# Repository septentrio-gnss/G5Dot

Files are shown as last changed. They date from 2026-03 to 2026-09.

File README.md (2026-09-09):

# G5Dot

| Role | Contact |
|---|---|
| Author | [laekaz](https://github.com/laekaz) |
| Maintainer  | [Septentrio GNSS GitHub User](githubuser@septentrio.com) |
| License | Open-Source Hardware License (CERN-OHL) |

<p align="center">
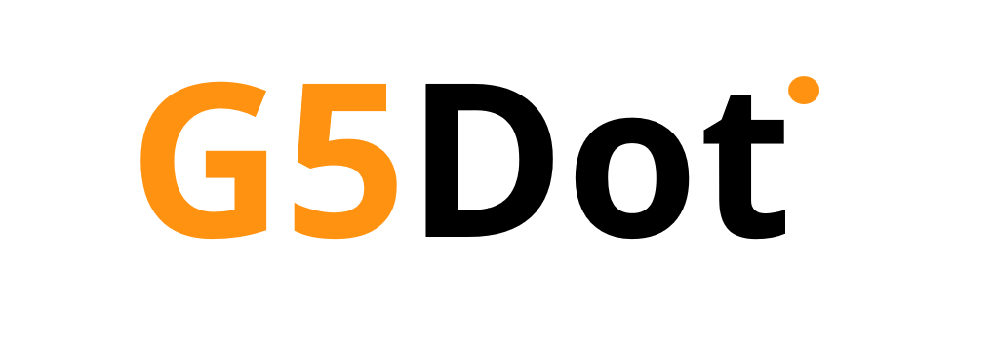
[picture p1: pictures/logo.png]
  
</p>
<p align="center">
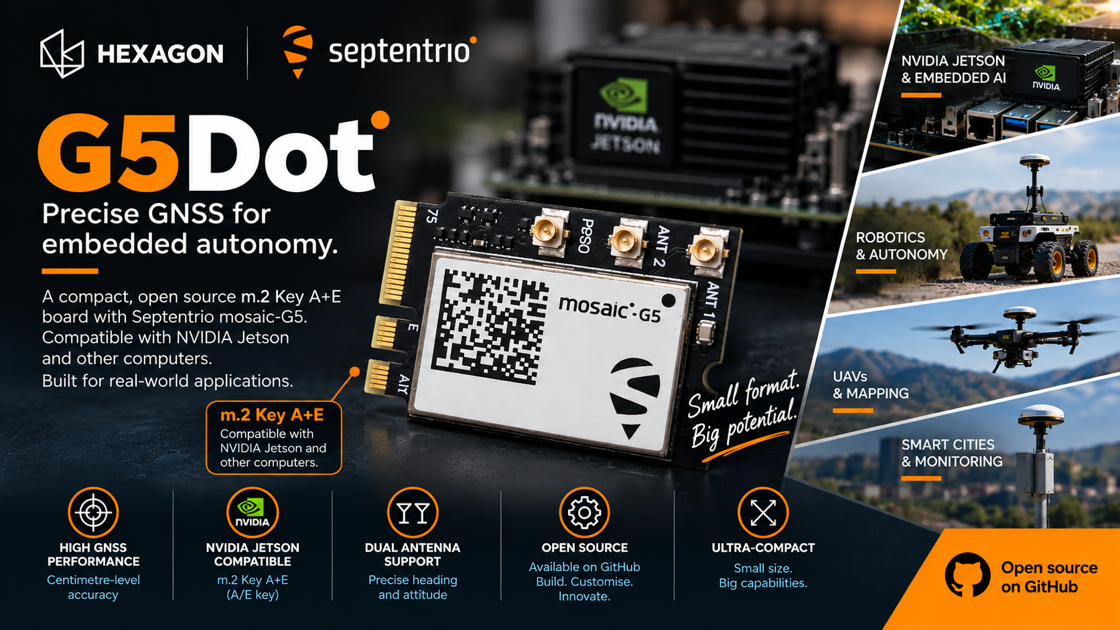
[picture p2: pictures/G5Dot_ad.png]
ad
  
</p>

This open source project is derived from the following original project located [here](https://github.com/anavsgmbh/M2_Mosaic-G5_Smart/tree/main)

# Table of Contents
* [Introduction to G5Dot](#introduction-to-g5dot)
  * [What is a G5Dot?](#what-is-a-g5dot)
  * [Who is Septentrio?](#who-is-septentrio)
  * [Where can I buy it?](#where-can-i-buy-it)
    * [Who is ANavS GmbH?](#who-is-anavs-gmbh)
* [Technology](#technology)
  * [What is a mosaic-G5 module?](#what-is-a-mosaic-g5-module)
  * [Other mosaic-G5 versions](#other-mosaic-g5-versions)
* [Why Open Source](#why-open-source)
* [Disclaimer](#disclaimer)
* [How to Produce](#how-to-produce)
  * [Deliverables](#deliverables)
  * [Ordering the mosaic-G5 Module](#ordering-mosaic-g5-module)
* [M.2 Form Factor](#m2-form-factor)
  * [Why M.2?](#why-m2)
  * [Why for NVIDIA?](#why-for-nvidia)
* [User Documentation](#user-documentation)
  * [Interfaces](#interfaces)
  * [Insert in NVIDIA Orin Development Kit](#insert-in-nvidia-orin-development-kit)
  * [Pinout for M.2 Key A+E Connector](#pinout-for-m2-key_ae-connector)
  * [Pinout for mosaic-G5 Module](#pinout-for-mosaic-g5-module)
  * [Antenna](#antenna)
  * [How to Get GNSS Data](#how-to-get-gnss-data)

* [Interface, Protocol & Electrical Specifications](#interface-protocol--electrical-specifications)

# Introduction to G5Dot
## What is a G5Dot?
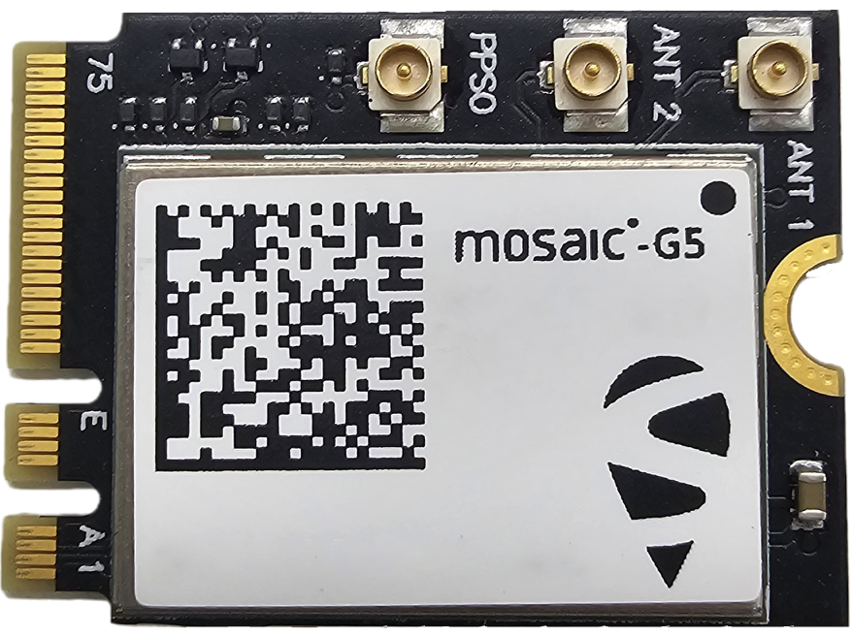
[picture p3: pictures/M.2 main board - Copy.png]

This is a compact, high precision GNSS (Global Navigation Satellite System) receiver card design for embedded computing platforms, ideal for industrial PCs such as NVIDIA Jetson. Its small size and low power consumption make it appropriate for applications where space and efficiency are critical. 

The design is based on the mosaic-G5 GNSS receiver, which supports multiple satellite systems and enables centimetre-level positioning accuracy. This open-source board was originally designed by ANavS GmbH.
## Who is Septentrio?


Septentrio is a leading company that designs, manufactures and sells high precision and multi-frequency GPS/GNSS receivers for demanding applications. Septentrio products are used in different industries including automotive, marine, construction, rail, machine control, logistics, precision agriculture, geographic information systems (GIS), Unmanned aerial vehicles (UAVs), survey, mapping and scientific applications. Septentrio’s receivers constantly deliver highly accurate and precise GNSS positioning, scalable to centimetre-level and designed to perform perfectly in challenging environments. 

Septentrio's technology offers high accuracy and reliability thanks to advanced GNSS algorithms as well as [Advanced interference Monitoring and mitigation (AIM+)](https://www.septentrio.com/en/learn-more/advanced-positioning-technology/aim-anti-jamming-protection) This protects your application against jamming (RF interference) and spoofing (malicious attacks).

For more information about Septentrio products go to [**https://www.septentrio.com/**](https://web.septentrio.com/GH-SSN-home).

## Where can i buy it?
The board is available for purchase from ANavS

Website: https://anavs.com/products/embedded-modules/gnss-card-g5/

### Who is ANavS GmbH
ANavS GmbH is a German company that develops high precision navigation and positioning systems. Their technology combines GNSS, inertial sensors (IMUs), and sensor fusion algorithms to provide accurate location and orientation.

For more details, visit the product page [here](https://anavs.com/products/embedded-modules/gnss-card-g5/) 

# Technology 
## What is a mosaic-G5 module?
The mosaic-G5 is a compact GNSS receiver module from Septentrio, engineered for high reliability and precise positioning. It integrates the latest multi-band, multi-constellation GNSS technology, providing accurate positions while minimizing power consumption. The receiver can access signals from all major satellite constellations, including GPS, Galileo, GLONASS, and BeiDou.

Different versions of the mosaic-G5 are available to suit various applications, as summarized below:

| Features | [mosaic-G5 P1](https://www.septentrio.com/en/products/gnss-receivers/gnss-receiver-modules/mosaic-g5-p1) | [mosaic-G5 P3](https://www.septentrio.com/en/products/gnss-receivers/gnss-receiver-modules/mosaic-G5-P3) | [mosaic-G5 P3H](https://www.septentrio.com/en/products/gnss-receivers/gnss-receiver-modules/mosaic-G5-P3H) |
|---|---|---|---|
| Functionality|High-precision positioning |High-precision positioning |Positioning + Heading|
| Use case |Robotics (e.g robotic mowers), GIS devices |UAV, Commercial mowers, Industrial Robotics, GIS and mapping applications |UAV, Commercial mowers, Industrial Robotics,GIS, mapping applications, sensor fusion and INS systems| 
| GNSS bands | Triple-band  | Quad-band | Quad-band |
| RTK support  | Yes | Yes | Yes |
| Dual antenna | | | Yes |
| Heading | | | Yes |

## Other mosaic-G5 versions
 You can use other [mosaic modules](https://www.septentrio.com/en/products/gnss-receivers?f%5B0%5D=type%3A604), but you need to pay attention to the functions and pins that could be exposed, then modify the design for your own project. 

## Why open-source 
This board is open-source to encourage collaboration, customization, and innovation. It makes it easy for developers, hobbyists, and integrators to combine high-precision GNSS positioning with platforms like NVIDIA, experiment, create spin-off projects, and adapt it for a wide range of robotics, autonomous systems, or industrial applications.

Open-source promotes shared development, letting users build on existing work and push the technology further. It also means you have access to editable design files and are free to modify, build or sell your own version.

## Disclaimer
This project is offered as-is. The main interfaces have been tested, but the design has not been fully checked or approved by the author or Septentrio. You are responsible for how you use it in your own projects. For guidance on working with Septentrio’s GNSS mosaic modules, we suggest reaching out to Septentrio directly.

Support website: https://www.septentrio.com/en/support

# How to produce
## Deliverables
This open-source project contains the following files for designers, producers and integrators around Septentrio's mosaic modules.

Both **Altium Designer** and **KiCad** design files are provided. You can choose either format according to your preferred PCB design workflow.

### Altium Designer

|Files |Description | 
|---|---|
|[G5Dot.PrjPcb](/G5Dot/G5Dot/G5Dot.PrjPcb) |Altium Project |
|[Cover_Page.SchDoc](/G5Dot/G5Dot/Cover_Page.SchDoc) |Cover page |
|[M.2_Key_A+E.SchDoc](/G5Dot/G5Dot/M.2_Key_A+E.SchDoc) |Schematics for M.2 KEY A+E |
|[Mosaic-G5.SchDoc](/G5Dot/G5Dot/Mosaic-G5.SchDoc) |Schematics for mosaic-G5 P3 module|
|[G5Dot.PrjPcbVariants](/G5Dot/G5Dot/G5Dot.PrjPcbVariants) |Introduction and variants |
|[BOM_G5Dot_REV_01.01_VARIANT_Mosaic-G5_P3H.xlsx](/BOM_G5Dot_REV_01.01_VARIANT_Mosaic-G5_P3H.xlsx)|Bill of Materials |
|[G5Dot_Schematics.pdf](/G5Dot_Schematics.pdf) |Schematics PDF |

### KiCad

| File | Description |
|---|---|
| [G5Dot.kicad_pro](./G5Dot/G5Dot%20Kicad/G5Dot.kicad_pro) | KiCad project |
| [Cover_Page.kicad_sch](./G5Dot/G5Dot%20Kicad/Cover_Page.kicad_sch) | Cover page schematic |
| [M.2_Key_A+E.kicad_sch](./G5Dot/G5Dot%20Kicad/M.2_Key_A+E.kicad_sch) | Schematics for the M.2 Key A+E interface |
| [Mosaic-G5.kicad_sch](./G5Dot/G5Dot%20Kicad/Mosaic-G5.kicad_sch) | Schematics for the mosaic-G5 P3 module |

## Ordering mosaic-G5 module

You can order the mosaics from Digi-Key, or you can contact Septentrio directly.

| mosaic-G5 versions | Septentrio | Digi-Key part_number| CompoTEK |
|---|---|---|---|
| mosaic-G5 P1 |[Septentrio_G5-P1](https://www.septentrio.com/en/products/gnss-receivers/gnss-receiver-modules/mosaic-g5-p1) | - |-|
| mosaic-G5 P3 | [Septentrio_G5-P3](https://www.septentrio.com/en/products/gnss-receivers/gnss-receiver-modules/mosaic-G5-P3) | [410501](https://www.digikey.com/en/products/detail/septentrio-inc/410501/28527327) | [sep_mosaic-G5_P3](https://shop.compotek.de/products/mosaic-G5-P3-p789238026)|
| mosaic-G5 P3H |[Septentrio_G5-P3H](https://www.septentrio.com/en/products/gnss-receivers/gnss-receiver-modules/mosaic-G5-P3H) | [410502](https://www.digikey.com/en/products/detail/septentrio-inc/410502/28527213) | [sep_mosaic-G5_P3H](https://shop.compotek.de/products/mosaic-G5-P3H-p790005981)|
|G5Dot| - | [100040](https://www.digikey.com/en/products/detail/anavs-gmbh/100040/28164182) |- |

# M.2 form factor
## Why M.2?
M.2 form factor is a standard interface used to provide a compact and flexible way to add extra functionality without redesigning the hardware. It is usually used in Laptops for Wi-Fi or SSDs, industrial PCs and embedded boards such as NVIDIA Jetson. 

The M.2 Key A+E connector can fit into a Key E and Key A slots. Key A and Key E modules are mechanically compatible with both Key A and Key E slots.  

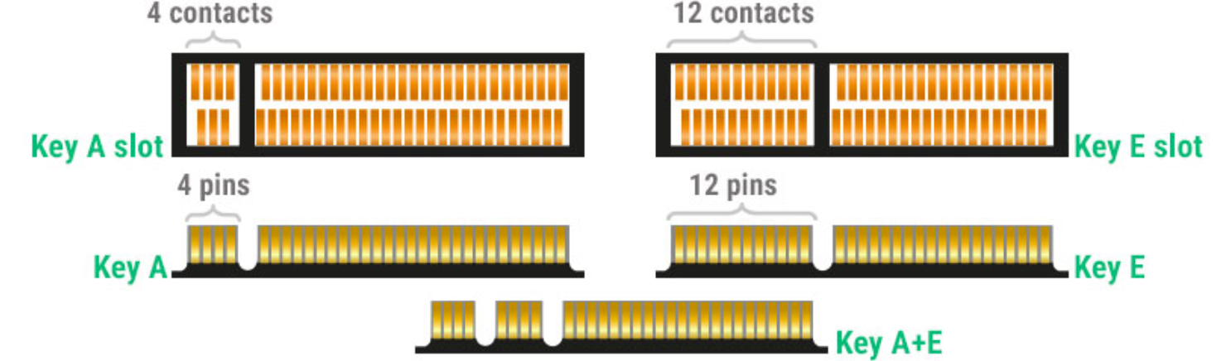
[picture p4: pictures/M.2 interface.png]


## Why for NVIDIA?
NVIDIA Jetson boards are small powerful AI computers designed for applications like robotics, drones and smart systems. They provide powerful GPU performance in a compact, energy-efficient system, making them ideal for real-time AI and embedded development.

Using the M.2 form factor for the mosaic-G5, allows developers already working in the NVIDIA ecosystem to easily add the GNSS module without redesigning their hardware.

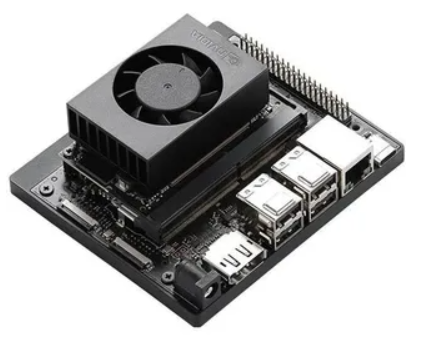
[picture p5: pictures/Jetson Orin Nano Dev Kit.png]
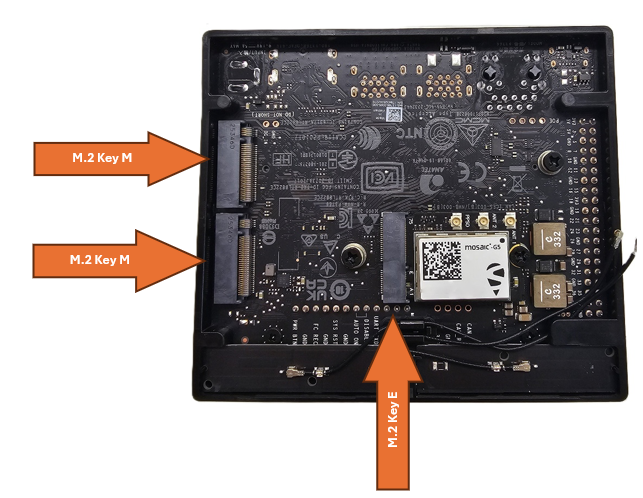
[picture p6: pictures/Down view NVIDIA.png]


# User documentation

## Interfaces
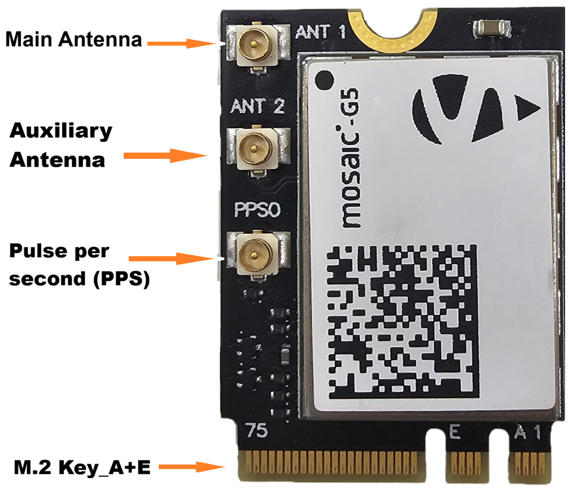
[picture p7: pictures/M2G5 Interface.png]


## Insert in NVIDIA Orin development kit
G5Dot can be easily connected to the NVIDIA Jetson board as shown: 

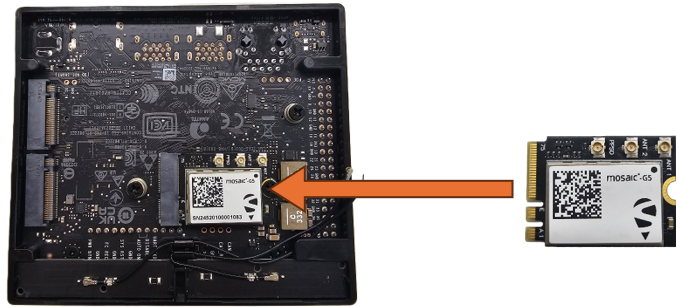
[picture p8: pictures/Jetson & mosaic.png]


You can insert the board on the underside of the NVIDIA Jetson board 

## Pinout for M.2 Key_A+E Connector 
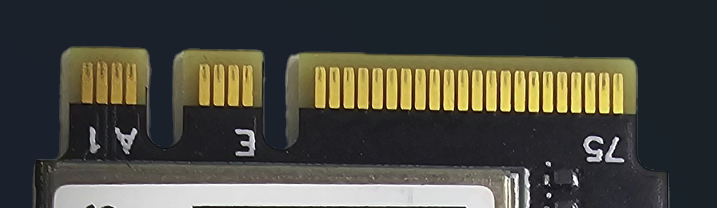
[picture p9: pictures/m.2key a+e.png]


| Pin # |Signal to the mosaic module|
|---|---|
| 3	 |USB D+ |
| 5	 |USB D- |
| 2,4,72,74	|power 3.3 V |
| 6 |External LED | 
| 16 | External LED | 
| GND	 |GND |

* USB: the USB interface handles both data communication and receiver configurations. Through this connection, the GNSS receiver module can send positioning data, satellite information, and timing messages.

* Power: the board is powered via 3.3 V supply lines on multiple pins to ensure stable operation. A clean and stable power source is important for reliable GNSS performance.

* LED: these pins can be used to drive external LEDs, which are helpful for quick visual feedback

## Pinout for mosaic-G5 module

| Pin # |mosaic module signals|
|---|---|
|2 |Antenna |
|5 |Antenna |
|12	 |USB D+ |
|13 |USB D- |
|14 |VBUS |
|42 | Pulse Per Second |
|44, 45 |power 3.3 V |
|52 |External LED | 
|53 | External LED | 
|54 |Antenna power 3.3 V  |
| GND	  |GND |

## Antenna

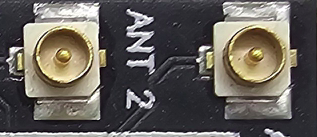
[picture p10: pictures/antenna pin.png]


The board exposes two RP-UMRF (micro RF) antenna connectors for GNSS signal reception. These connectors are designed for 50 Ω antennas and provide the interface for connecting external GNSS antennas to the module.

The connectors typically serve as MAIN (primary) and AUX (secondary) inputs, enabling support for advanced features such as dual-band reception and high-precision positioning (e.g., RTK)

## How to get GNSS Data
* Insert the G5Dot into the M.2 slot.
* Connect the GNSS antenna to the antenna connector
* Configure the receiver 

## Interface, Protocol & Electrical Specifications
Interface
* USB (device 2.0 HS up to 480 Mbps)
* Configure PPS via the u.FL connector

Protocols
* SBF (Septentrio Binary Format)
* NMEA
* RTCM v3.x (MSM included)

The official Septentrio mosaic-G5 driver can be used

Electrical
* Input voltage: 3.3 V +/- 5%
* Power consumption:
 * Typical: 0.4-0.6 W 
 * Max: 0.9 W 
* Antenna bias voltage: 3.3 V

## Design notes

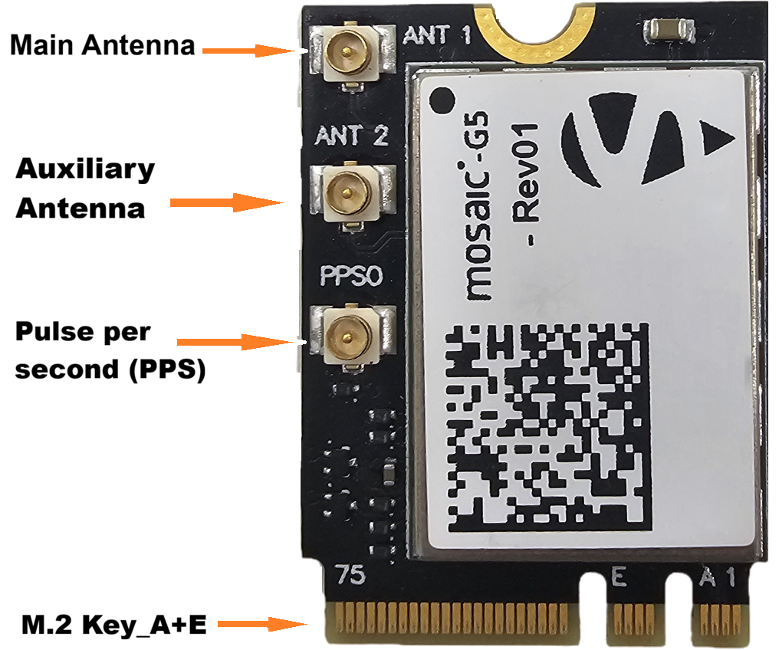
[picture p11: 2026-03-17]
pictures/M2G5 Interface black (2).png

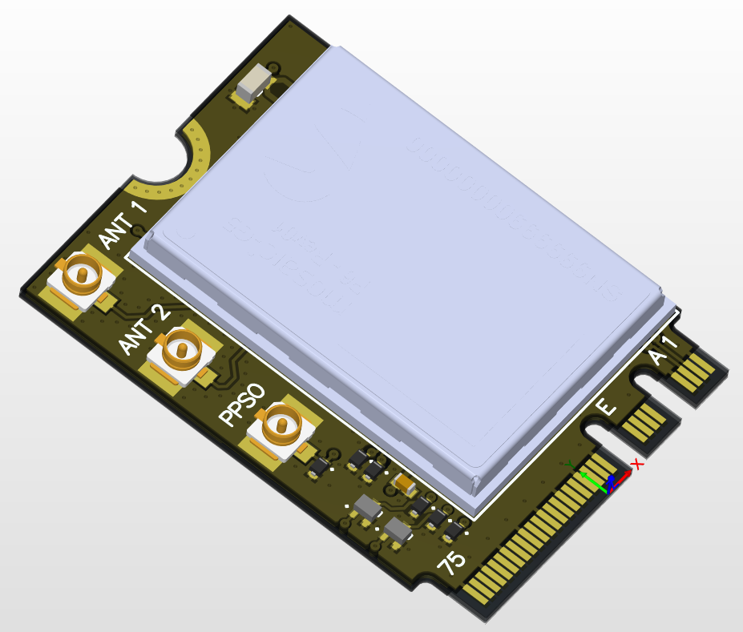
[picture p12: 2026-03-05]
preview.png

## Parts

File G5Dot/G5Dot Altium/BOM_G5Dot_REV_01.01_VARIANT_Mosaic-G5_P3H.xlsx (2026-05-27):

 | Bill of Materials
 | Project Title: | BOM for Variant [Mosaic-G5_P3H] of BOM Document [G5Dot.BomDoc] |  |  |  |  | Geenhill Campus
 | Project File Name: | G5Dot.PrjPcb |  |  |  |  | Interleuvenlaan 15i
 | Assembly Variant: | Mosaic-G5_P3H |  |  |  |  | 3001 Leuven
 | Report Date: | 12.06.2025 | 11:15 |  |  |  | Belgium
Name | Description | Designator | Quantity | Manufacturer1 | MPN1 | Supplier1 | SPN1
C1608X5R0J226M080AC | MLCC, 22 uF, 0603, 6.3 V, 20%, X5R | C1 | 1 | TDK | C1608X5R0J226M080AC | Newark | 04X3240
GCM155R71H104KE02D | MLCC, 100 nF, 0402, 50 V, 10%, X7R | C2 | 1 | Murata | GCM155R71H104KE02D | Newark | 96Y9214
ESD9R3.3ST5G | ESD9R3.3S Series 4.8 V 0.5 pF Uni-Directional ESD Protection Diode - SOD-923 | D1, D2, D3, D4, D5, D6 | 6 | ON Semiconductor | ESD9R3.3ST5G | Newark | 13P3802
636101112001 | Rf Conn, Umrf, Jack, 50 Ohm, Pcb Rohs Compliant: Yes | J2, J3, J4 | 3 | Wurth Electronics | 636101112001 | Digikey | 732-636101112001CT-ND
NTK3043NT1G | Single N-Channel Small Signal MOSFET with ESD Protection 20V, 285mA, 3.4Ω | Q1, Q2 | 2 | ON Semiconductor | NTK3043NT1G | Mouser | 863-NTK3043NT1G
mosaic-G5-P3H | mosaic-G5 GNSS Module - Low-power multi-band multi-constellation GNSS receiver. | U1 | 1 | Septentrio | 410502 | Digikey | 2771-410502-ND
PCB | Printed Circuit Board | UF1 | 1

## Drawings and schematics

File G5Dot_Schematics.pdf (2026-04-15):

# M.2 Dual Key A+E Card with Mosaic-G5 GNSS Module

# Low-power multi-band multi-constellation GNSS receiver

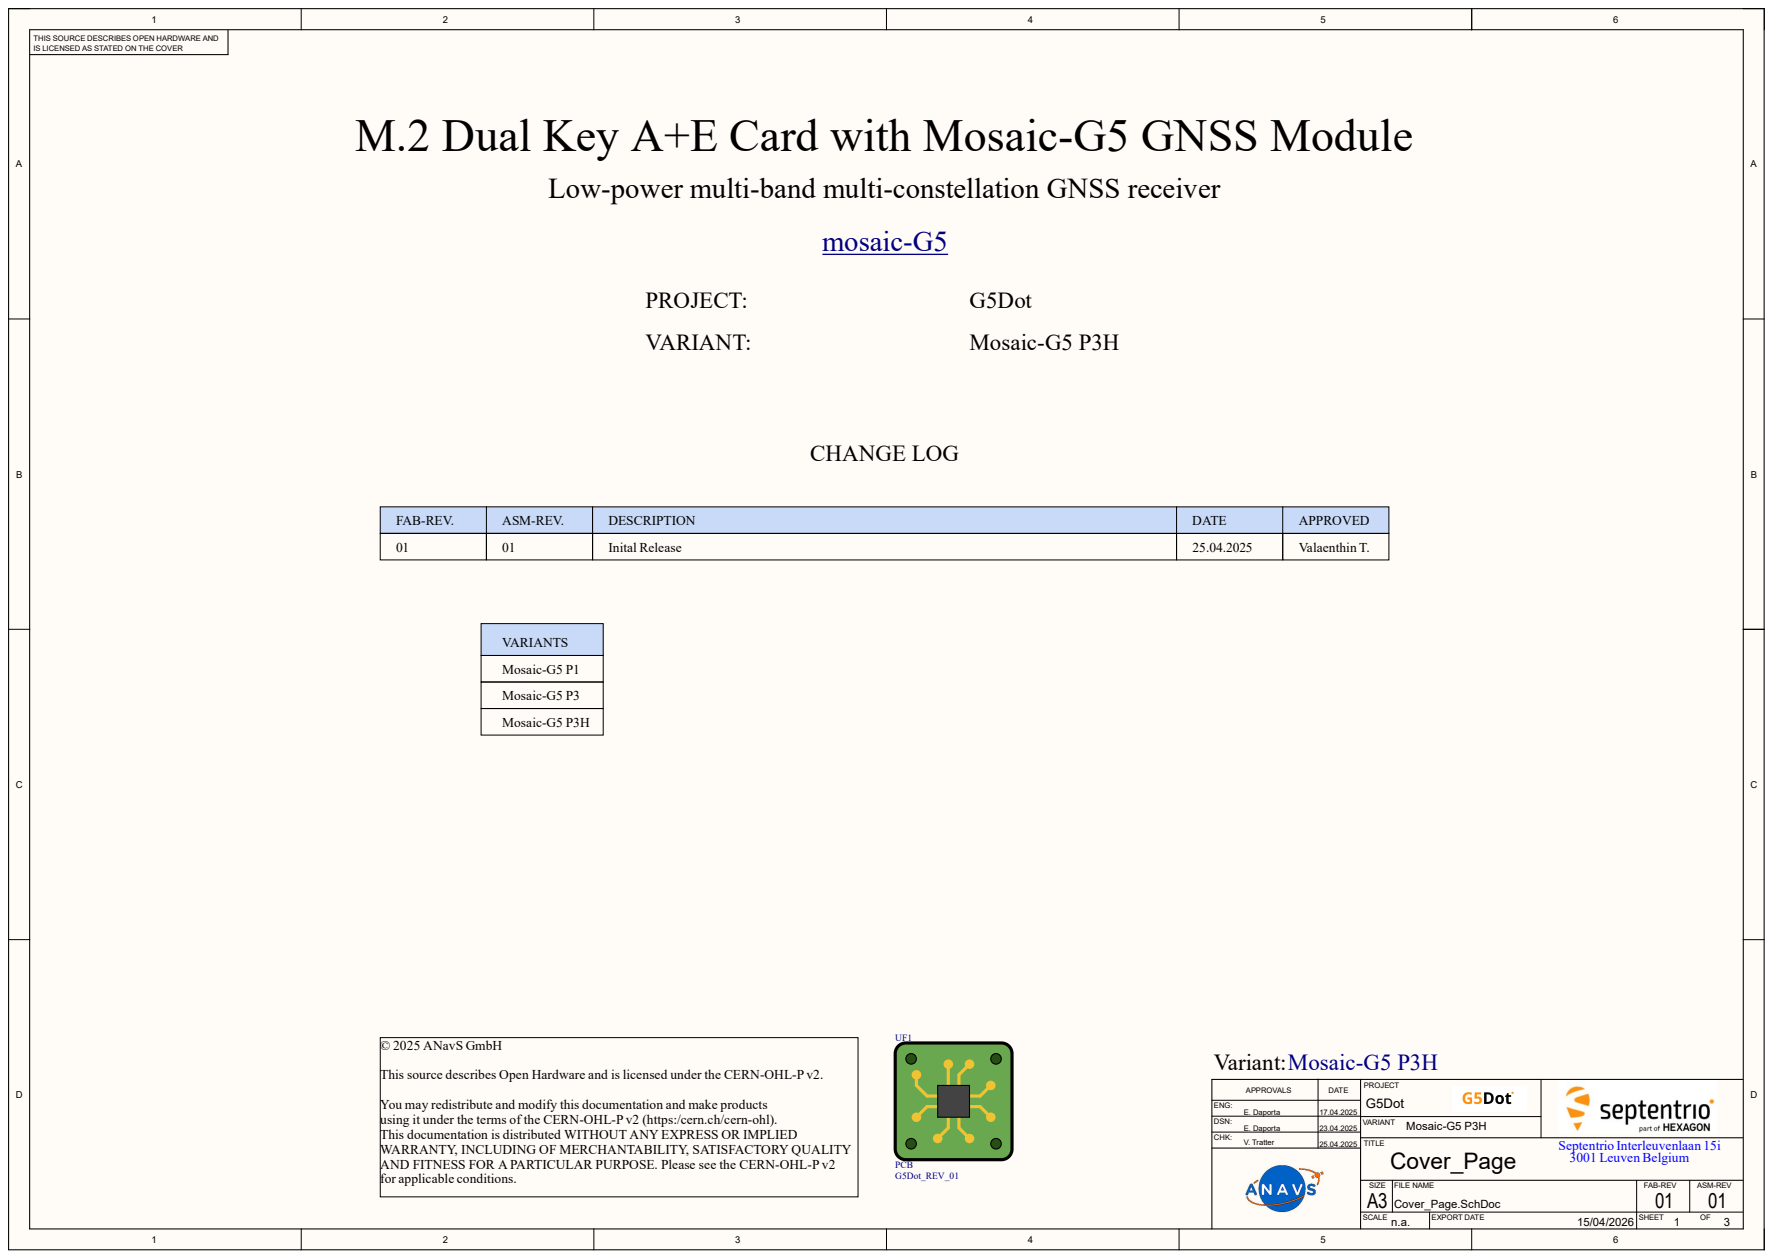
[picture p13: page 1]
Cover_Page; TITLE; Variant:Mosaic-G5 P3H; mosaic-G5; ASM-REV.; DESCRIPTION; DATE; APPROVED; 01 Inital Release; FAB-REV.; Valaenthin T.; CHANGE LOG; © 2025 ANavS GmbH; PROJECT:; G5Dot; VARIANT:; Mosaic-G5 P3H; Septentrio Interleuvenlaan 15i; G5Dot_REV_01; PCB; VARIANTS; Mosaic-G5 P1; Mosaic-G5 P3; 3001 Leuven Belgium

THIS SOURCE DESCRIBES OPEN HARDWARE AND
IS LICENSED AS STATED ON THE COVER

This source describes Open Hardware and is licensed under the CERN-OHL-P v2.

APPROVALS | DATE | PROJECT G5Dot | Septentrio * Belgium

You may redistribute and modify this documentation and make products
using it under the terms of the CERN-OHL-P v2 (https:/cern.ch/cern-ohl).
This documentation is distributed WITHOUT ANY EXPRESS OR IMPLIED
WARRANTY, INCLUDING OF MERCHANTABILITY, SATISFACTORY QUALITY
AND FITNESS FOR A PARTICULAR PURPOSE. Please see the CERN-OHL-P v2
for applicable conditions.

ENG: E. Daporta | 17.04.2025
DSN: E. Daporta | 23.04.2025 | VARIANT Mosaic-G5 P3H
CHK: V. Tratter | 25.04.2025

SIZE A3 Cover_Page.SchDoc | FILE NAME | FAB-REV | ASM-REV 01

SCALE n.a. | 15/04/2026 EXPORT DATE | SHEET OF

## M.2 Key A+E Card

# M.2 Dual Key A+E Edge Connector

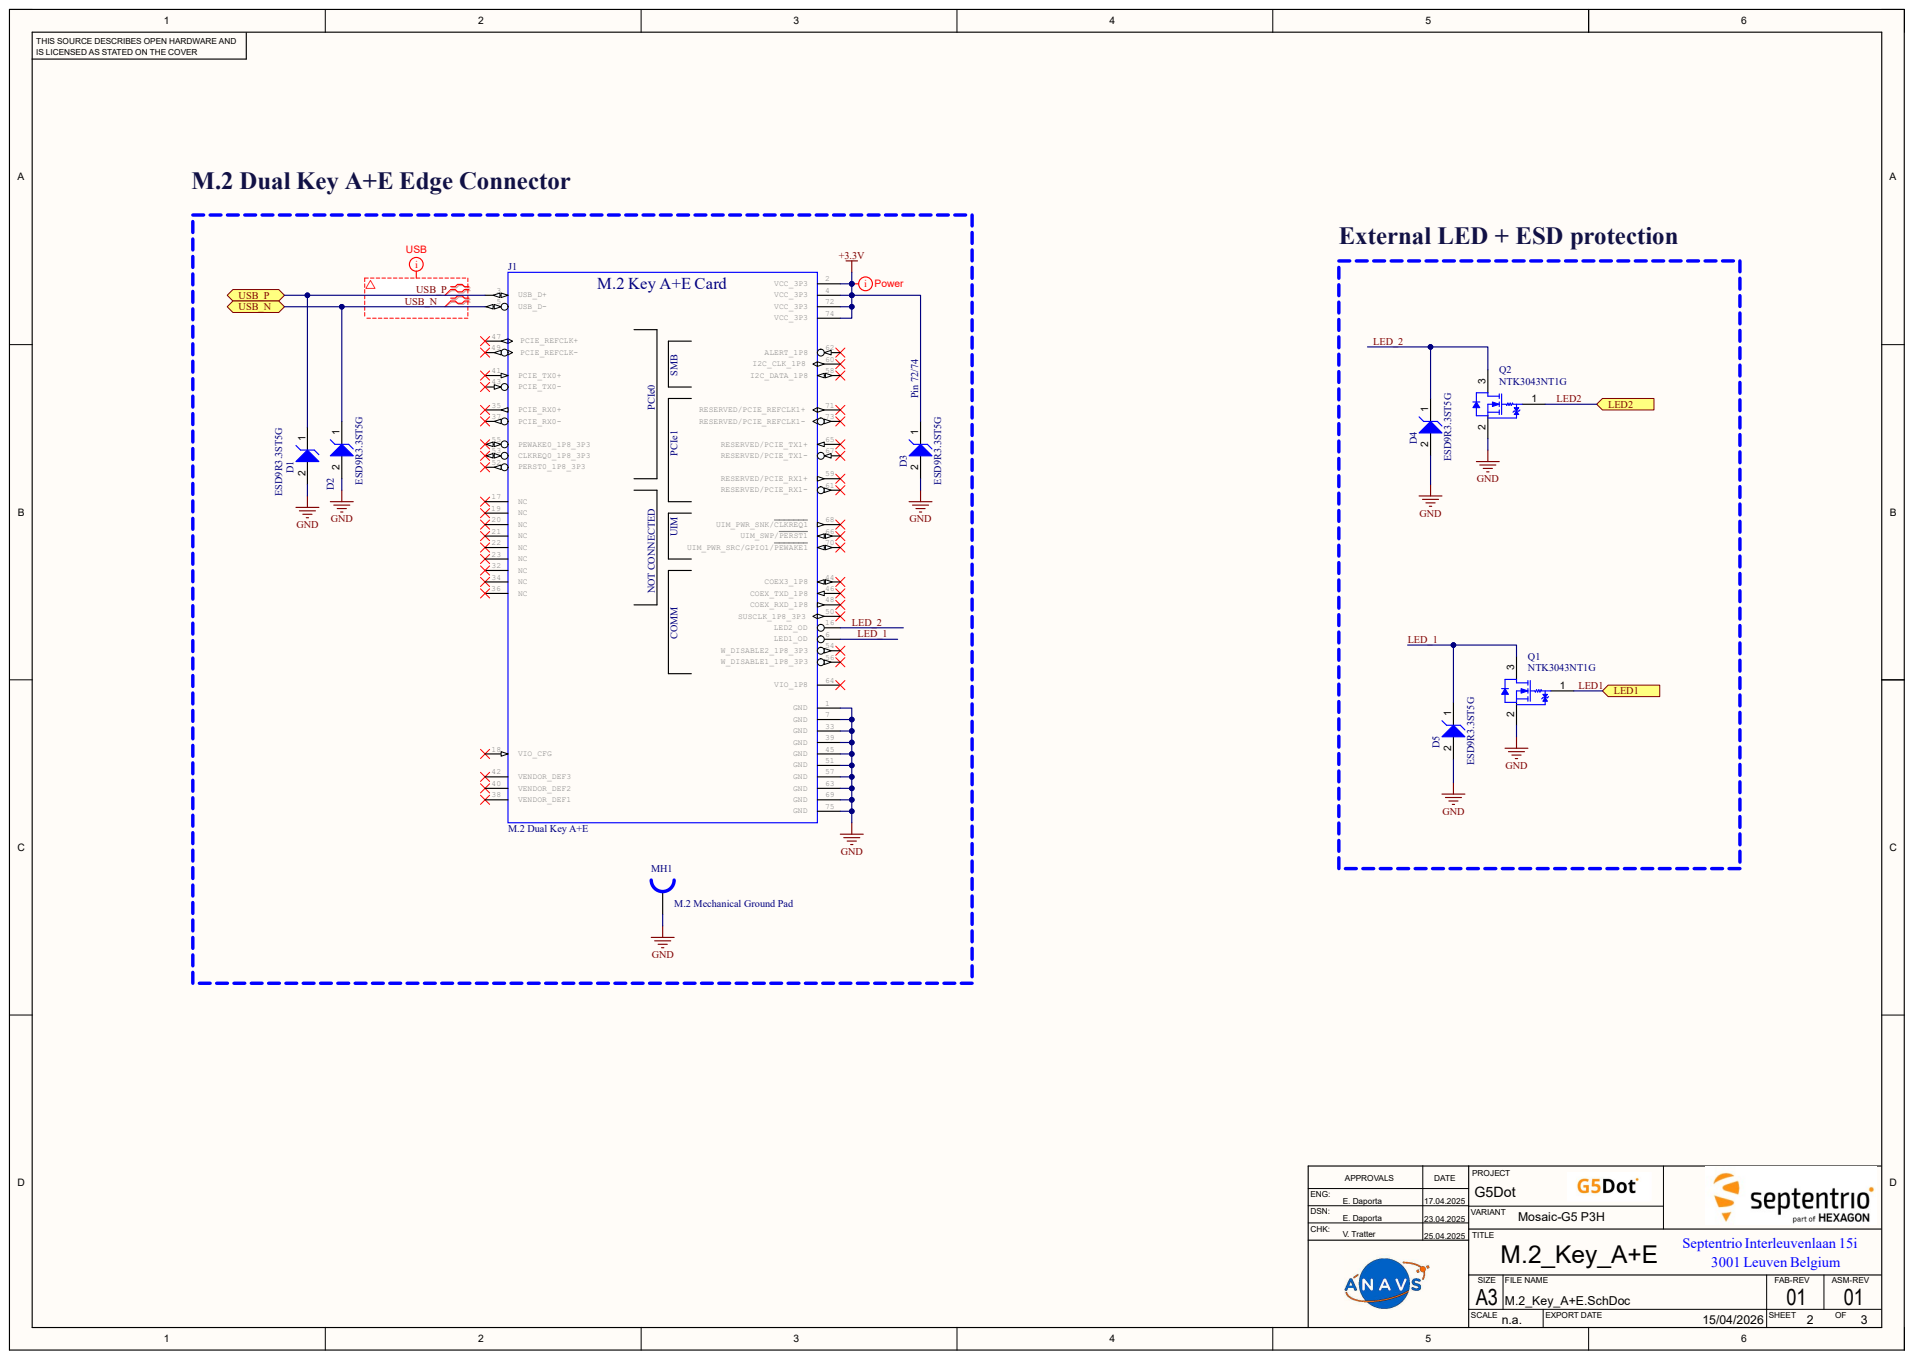
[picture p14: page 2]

External LED + ESD protection

APPROVALS | DATE | PROJECT G5Dot | Septentrio Interleuvenlaan 15i 3001, Leuven Belgium

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

## Main Power Supply

## Clock Frequency Reference

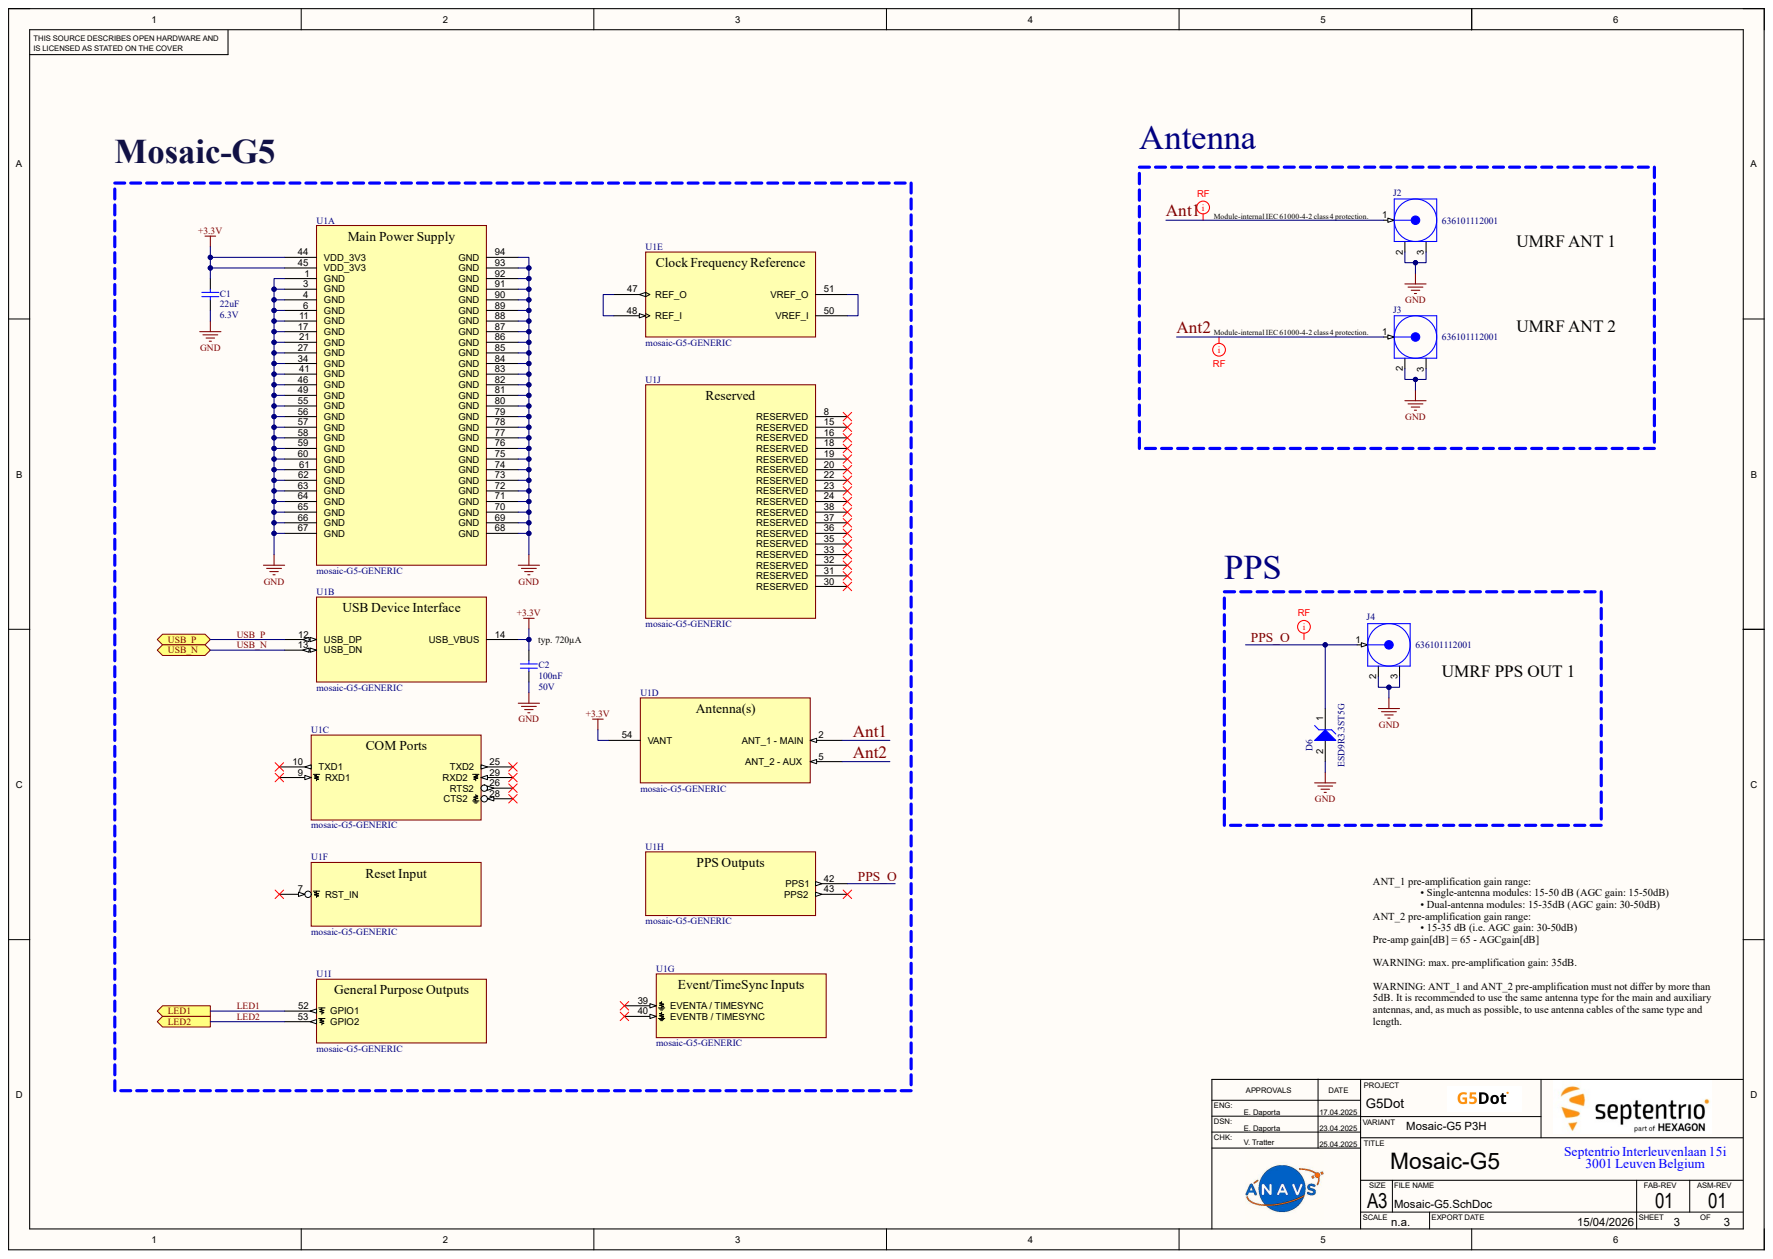
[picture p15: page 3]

Module-internal IEC 61000-4-2 class 4 protection.

ANT_1 pre-amplification gain range:

• Single-antenna modules: 15-50 dB (AGC gain: 15-50dB)
• Dual-antenna modules: 15-35dB (AGC gain: 30-50dB)

ANT_2 pre-amplification gain range:

Pre-amp gain[dB] = 65 - AGCgain[dB]

WARNING: max. pre-amplification gain: 35dB.

WARNING: ANT_1 and ANT_2 pre-amplification must not differ by more than
5dB. It is recommended to use the same antenna type for the main and auxiliary
antennas, and, as much as possible, to use antenna cables of the same type and
length.

APPROVALS | DATE | PROJECT G5Dot | Septentrio Interleuvenlaan 15i 3001, Leuven Belgium

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

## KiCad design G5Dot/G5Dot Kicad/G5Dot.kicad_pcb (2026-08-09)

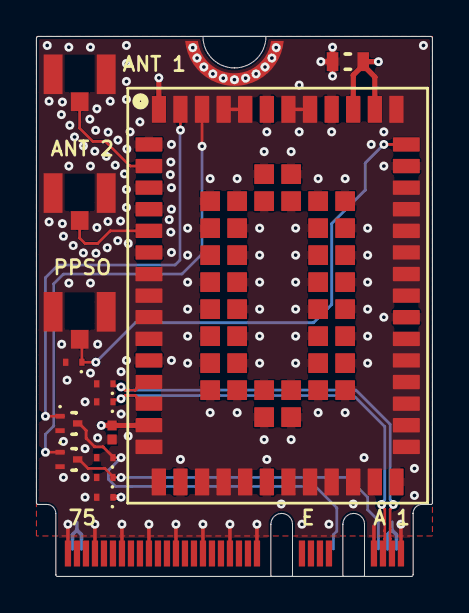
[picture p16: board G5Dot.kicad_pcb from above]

Board: 4 copper layers, 22.0 x 30.0 mm, 16 parts (0 on the bottom side), 13 nets.

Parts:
C1: C1608X5R0J226M080AC; CAPC1608X100X20ML10
C2: GCM155R71H104KE02D; CAP0402C
D1, D2, D3, D4, D5, D6: ESD9R3.3ST5G; ONSC-SOD-923-2-514AB-01_V
J1: M.2 Dual Key A+E; M.2 Key A+E card-Footprint
J2, J3, J4: 636101112001; 63610111x001
MH1: M.2 Mechanical Ground Pad; M.2 Mechanical Ground Pad Footprint
Q1, Q2: NTK3043NT1G; ONSC-SOT-723-3-631AA-01_V
U1: mosaic-G5-GENERIC; mosaic-G5-GENERIC-Footprint

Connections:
+3.3V: C1.2, C2.2, D3.1, J1.2, J1.4, J1.72, J1.74, U1.14, U1.44, U1.45, U1.54
GND: C1.1, C2.1, D1.2, D2.2, D3.2, D4.2, D5.2, D6.2, J1.1, J1.7, J1.33, J1.39, J1.45, J1.51, J1.57, J1.63, J1.69, J1.75, J2.2, J2.3, J3.2, J3.3, J4.2, J4.3, MH1.0, Q1.2, Q2.2, U1.1, U1.3, U1.4, U1.6, U1.11, U1.17, U1.21, U1.27, U1.34, U1.41, U1.46, U1.49, U1.55, U1.56, U1.57, U1.58, U1.59, U1.60, U1.61, U1.62, U1.63, U1.64, U1.65, U1.66, U1.67, U1.68, U1.69, U1.70, U1.71, U1.72, U1.73, U1.74, U1.75, U1.76, U1.77, U1.78, U1.79, U1.80, U1.81, U1.82, U1.83, U1.84, U1.85, U1.86, U1.87, U1.88, U1.89, U1.90, U1.91, U1.92, U1.93, U1.94
Led1: Q1.1, U1.52
Led2: Q2.1, U1.53
NetD4_1: D4.1, J1.16, Q2.3
NetD5_1: D5.1, J1.6, Q1.3
NetD6_1: D6.1, J4.1, U1.42
NetJ2_1: J2.1, U1.2
NetJ3_1: J3.1, U1.5
NetU1_47: U1.47, U1.48
NetU1_50: U1.50, U1.51
USB_N: D2.1, J1.5, U1.13
USB_P: D1.1, J1.3, U1.12

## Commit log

2026-03-07 Inserting pictures
2026-03-13 HW files update
    [BOM_MosaicM2G5_REV_01.01_VARIANT_Mosaic-G5_P3H.xlsx, Cover_Page.SchDoc, M.2_Key_A+E.SchDoc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]
2026-03-18 SAME FILES
    [BOM_MosaicM2G5_REV_01.01_VARIANT_Mosaic-G5_P3H.xlsx, Cover_Page.SchDoc, M.2_Key_A+E.SchDoc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]
2026-03-18 bom addition
    [BOM_M2_Mosaic-G5_Smart_REV_01.01_VARIANT_Mosaic-G5_P6H.xlsx]
2026-03-18 Update M.2 main board - Copy.png
2026-03-24 KiCAD update
    [BOM_M2_Mosaic-G5_Smart_REV_01.01_VARIANT_Mosaic-G5_P6H.xlsx, BOM_MosaicM2G5_REV_01.01_VARIANT_Mosaic-G5_P3H.xlsx, Cover_Page.SchDoc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]
2026-04-15 updating project name
    [BOM_MosaicM2G5_REV_01.01_VARIANT_Mosaic-G5_P3H.xlsx, G5Dot.PcbDoc, G5Dot.PrjPcb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]
2026-04-15 HW files update logo
    [BOM_G5Dot_REV_01.01_VARIANT_Mosaic-G5_P3H.xlsx, BOM_MosaicM2G5_REV_01.01_VARIANT_Mosaic-G5_P3H.xlsx, Cover_Page.SchDoc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]
2026-04-15 update hw files
    [BOM_G5Dot_REV_01.01_VARIANT_Mosaic-G5_P3H.xlsx, Cover_Page.SchDoc, G5Dot.PcbDoc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]
2026-04-15 hw files update name
    [BOM_G5Dot_REV_01.01_VARIANT_Mosaic-G5_P3H.xlsx, Cover_Page.SchDoc, G5Dot.PcbDoc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]
2026-07-20 KiCad design files
    Transformed the Altium files to KiCad
    [BOM_G5Dot_REV_01.01_VARIANT_Mosaic-G5_P3H.xlsx, Cover_Page.SchDoc, Cover_Page.kicad_sch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]
2026-08-09 measurements on PCB
    [G5Dot.kicad_pcb]

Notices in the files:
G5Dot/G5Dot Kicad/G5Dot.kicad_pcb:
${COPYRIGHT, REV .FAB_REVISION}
